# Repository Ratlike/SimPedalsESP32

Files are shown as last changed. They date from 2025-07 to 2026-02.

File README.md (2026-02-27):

# SimPedalsESP32

DIY sim racing pedals using an ESP32-S3. Supports brake, accelerator, clutch, and handbrake — shows up as a USB gamepad on your PC.

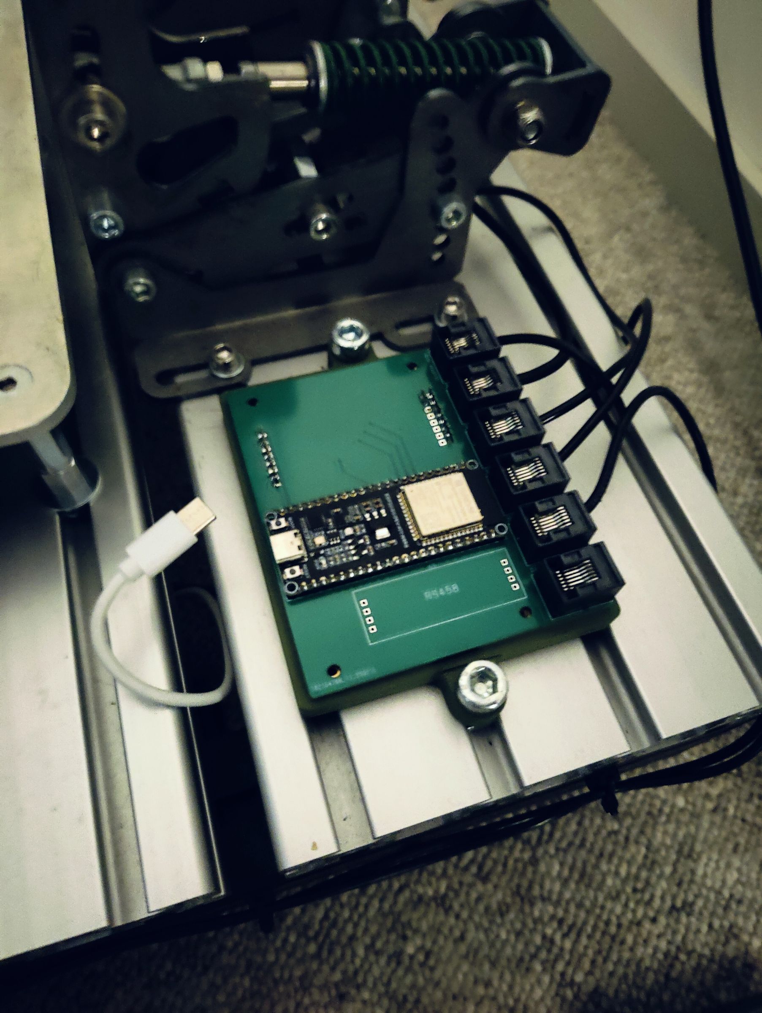
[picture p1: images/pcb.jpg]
PCB


## Hardware

- **ESP32-S3** microcontroller
- **Brake** — load cell + ADS1256 ADC
- **Accelerator & Clutch** — Hall-effect sensors
- **Handbrake** — load cell + HX711 ADC
- **2 buttons** for shifter / calibration

The `hardware/` folder has the KiCad PCB project and STEP files for a 3D-printed case.

## Building

Arduino IDE project targeting the ESP32-S3. Install the ESP32 board package, then add these libraries:

- [ADS1256](https://github.com/adienakhmad/ADS1256)
- [Joystick_ESP32S2](https://github.com/schnoog/Joystick_ESP32S2)
- [HX711](https://github.com/bogde/HX711)
- [Bounce2](https://github.com/thomasfredericks/Bounce2)

Open `SimPedalsESP32.ino` and upload.

## Calibration

1. Open a serial monitor at 115200 baud.
2. Hold **Button 1** for 3 seconds to enter calibration mode.
3. Press **Button 2** to cycle through pedals.
4. Leave each pedal at rest for 2 seconds, then press it to its max. The serial monitor shows the current raw value, min, and max in real time.
5. Hold **Button 1** for 3 seconds to save and exit.

Calibration is saved to flash and persists across power cycles.

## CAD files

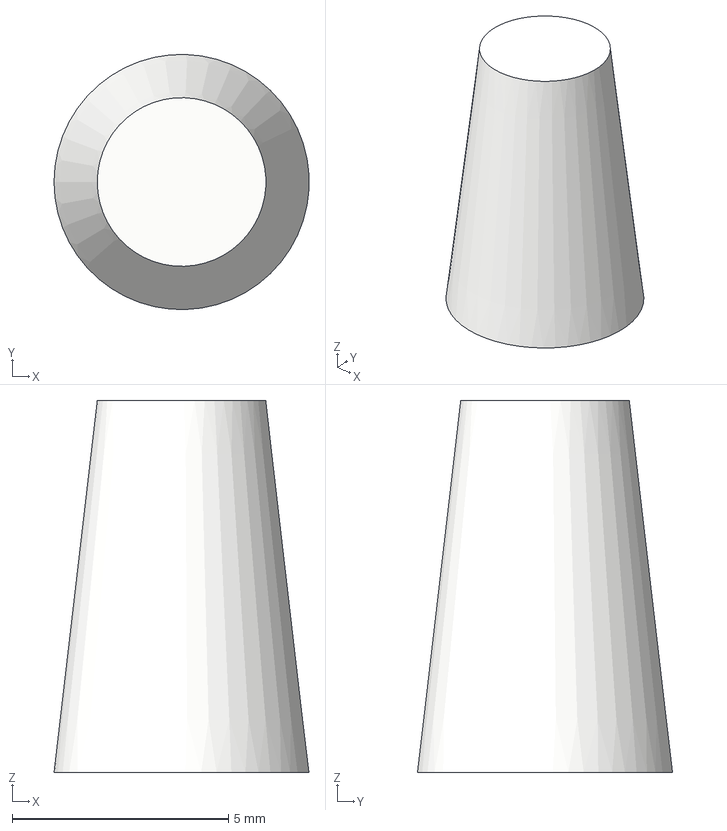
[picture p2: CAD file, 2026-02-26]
hardware/Case/LightGuide.step
5.89 x 5.90 x 8.60 mm

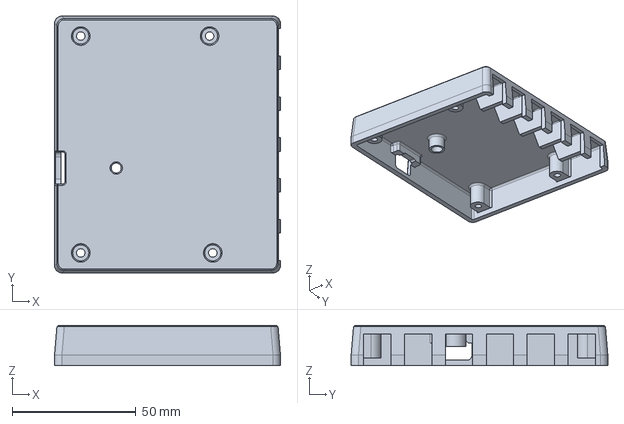
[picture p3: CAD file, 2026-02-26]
hardware/Case/Lid.step
91.3 x 103.8 x 16.2 mm

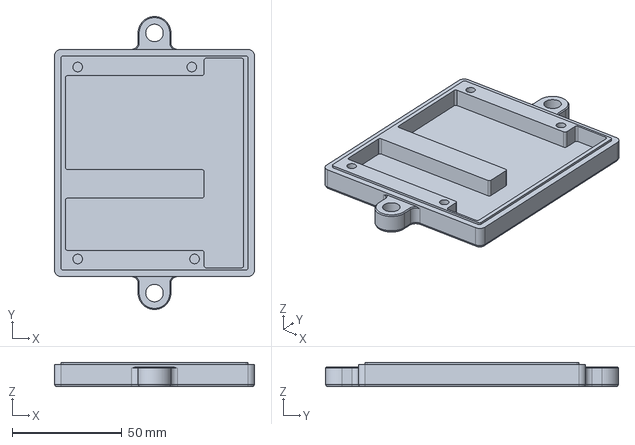
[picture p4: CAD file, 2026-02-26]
hardware/Case/Bottom.step
91.3 x 133.8 x 11.0 mm

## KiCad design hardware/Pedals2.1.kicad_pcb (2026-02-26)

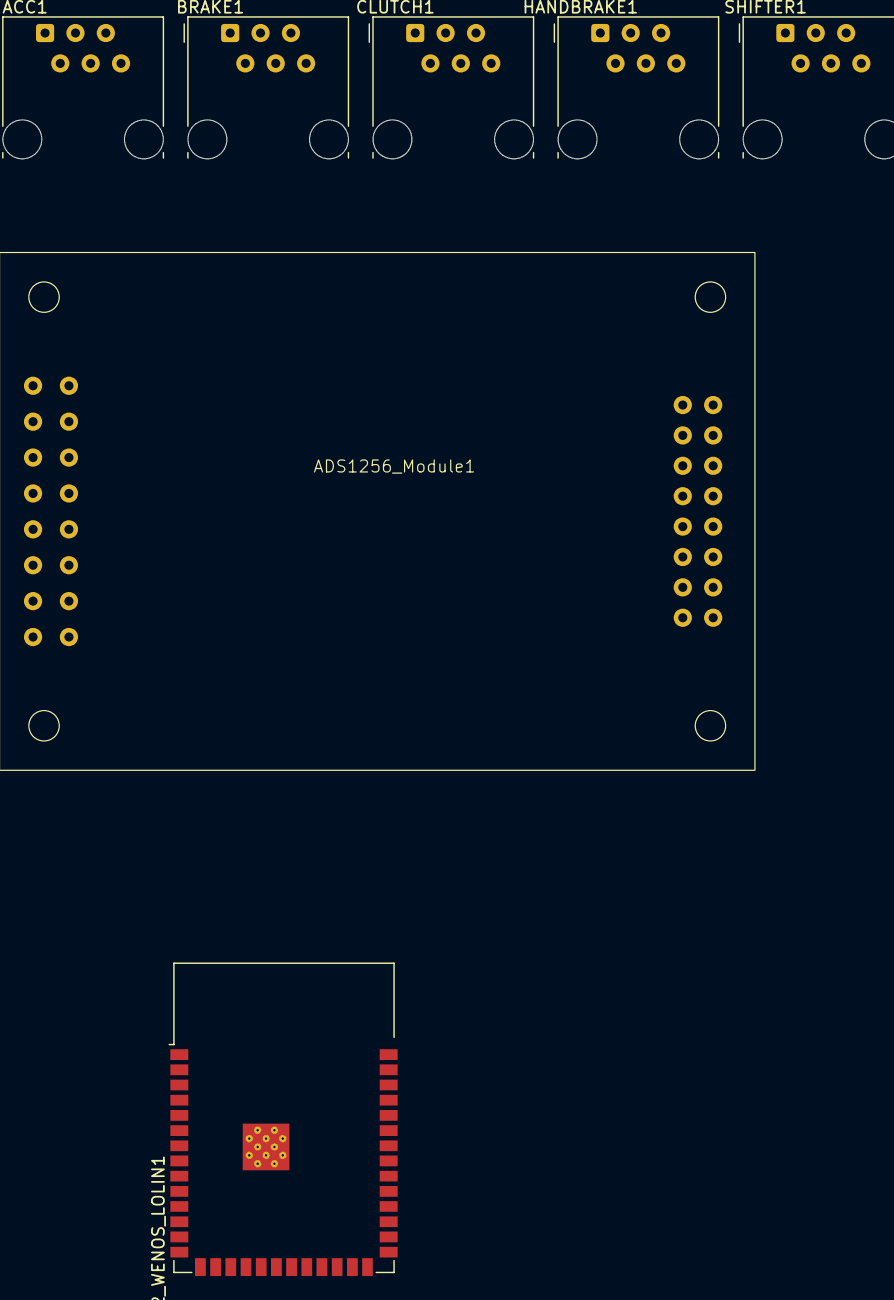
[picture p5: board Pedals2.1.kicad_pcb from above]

Board: 2 copper layers, 7 parts (0 on the bottom side), 2 nets, no tracks yet.

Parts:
ACC1: RJ12; RJ12_Amphenol_54601-x06_Horizontal
ADS1256_Module1: ADS1256 board
BRAKE1: RJ12; RJ12_Amphenol_54601-x06_Horizontal
CLUTCH1: RJ12; RJ12_Amphenol_54601-x06_Horizontal
ESP32_WENOS_LOLIN1: ESP32-S3-WROOM-1
HANDBRAKE1: RJ12; RJ12_Amphenol_54601-x06_Horizontal
SHIFTER1: RJ12; RJ12_Amphenol_54601-x06_Horizontal

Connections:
+3V3: ACC1.1, ACC1.2, BRAKE1.1, BRAKE1.2, CLUTCH1.1, CLUTCH1.2, HANDBRAKE1.1, HANDBRAKE1.2, SHIFTER1.1, SHIFTER1.2
GND: ACC1.5, ACC1.6, BRAKE1.5, BRAKE1.6, CLUTCH1.5, CLUTCH1.6, HANDBRAKE1.5, HANDBRAKE1.6, SHIFTER1.5, SHIFTER1.6

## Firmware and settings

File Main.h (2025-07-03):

// Main.h
#pragma once
//#include <ADS1256.h>

//#define PRINT_TASK_FREE_STACKSIZE_IN_WORDS

/********************************************************************/
/*                      Other defines       */
/********************************************************************/

// 2.0kHz
#define ADC_SAMPLE_RATE ADS1256_DRATE_2000SPS

/********************************************************************/
/*                      Loadcell defines                            */
/********************************************************************/
#define LOADCELL_WEIGHT_RATING_KG 200.0f
#define LOADCELL_EXCITATION_V 5.0f
#define LOADCELL_SENSITIVITY_MV_V 2.0f

// ADC defines
#define PIN_SCK 6    // 16 -->SCLK
#define PIN_MOSI 7   // 17 --> DIN
#define PIN_MISO 15  // 18 --> DOUT
#define PIN_DRDY 16  // 19 --> DRDY
#define PIN_CS 17    // 21 --> CS
#define PIN_RST 18   // 18 --> PDOWN

/********************************************************************/
/*                       Other input pins                           */
/********************************************************************/

#define CONTROLLER_BUTTON_COUNT 2
#define SHIFTER1_PIN 4
#define SHIFTER2_PIN 5
#define ACCEL_PIN_1 9
#define ACCEL_PIN_2 10
#define CLUTCH_PIN_1 11
#define CLUTCH_PIN_2 12

// HX711 pins (for handbrake)
#define HANDBRAKE_DOUT 1
#define HANDBRAKE_SCK 2

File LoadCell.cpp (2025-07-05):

// LoadCell.cpp
#include "LoadCell.h"

#include <SPI.h>
#include <ADS1256.h>
#include "Main.h"

static const float ADC_CLOCK_MHZ = 7.68f; // crystal frequency used on ADS1256
static const float ADC_VREF = 2.5f;       // voltage reference

static const int NUMBER_OF_SAMPLES_FOR_LOADCELL_OFFFSET_ESTIMATION = 1000;
static const float DEFAULT_VARIANCE_ESTIMATE = 0.2f * 0.2f;
static const float LOADCELL_VARIANCE_MIN = 0.001f;
// static const float CONVERSION_FACTOR = LOADCELL_WEIGHT_RATING_KG / (LOADCELL_EXCITATION_V * (LOADCELL_SENSITIVITY_MV_V/1000));

float updatedConversionFactor_f64 = 1.0f;
#define CONVERSION_FACTOR LOADCELL_WEIGHT_RATING_KG / (LOADCELL_EXCITATION_V * (LOADCELL_SENSITIVITY_MV_V / 1000.0f))

uint8_t global_channel0_u8, global_channel1_u8, global_channel2_u8;

ADS1256 &ADC()
{
  static ADS1256 adc(
      ADC_CLOCK_MHZ,
      ADC_VREF,
      /*useresetpin=*/false,
      PIN_DRDY, PIN_SCK, PIN_MISO, PIN_MOSI, PIN_CS); // RESETPIN is permanently tied to 3.3v

  static bool firstTime = true;
  if (firstTime)
  {
    // ensure the ADS1256 RST pin is held high via internal pull-up
    pinMode(PIN_RST, INPUT_PULLUP);
    digitalWrite(PIN_RST, HIGH);

    Serial.println("Starting ADC");
    adc.initSpi(ADC_CLOCK_MHZ);
    delay(1000);

    Serial.println("ADS: send SDATAC command");
    // adc.sendCommand(ADS1256_CMD_SDATAC);

    // start the ADS1256 with a certain data rate and gain
    adc.begin(ADC_SAMPLE_RATE, ADS1256_GAIN_64, false);

    Serial.println("ADC Started");

    adc.waitDRDY(); // wait for DRDY to go low before changing multiplexer register
    if (fabs(CONVERSION_FACTOR) > 0.01f)
    {
      adc.setConversionFactor(CONVERSION_FACTOR);
    }
    else
    {
      adc.setConversionFactor(1);
    }
    firstTime = false;
  }

  return adc;
}

void LoadCell_ADS1256::setLoadcellRating(uint8_t loadcellRating_u8) const
{
  ADS1256 &adc = ADC();
  float originalConversionFactor_f64 = CONVERSION_FACTOR;

  updatedConversionFactor_f64 = 1.0f;
  if (LOADCELL_WEIGHT_RATING_KG > 0)
  {
    updatedConversionFactor_f64 = 2.0f * ((float)loadcellRating_u8) * (CONVERSION_FACTOR / LOADCELL_WEIGHT_RATING_KG);
  }
  Serial.print("OrigConversionFactor: ");
  Serial.print(originalConversionFactor_f64);
  Serial.print(",     NewConversionFactor:");
  Serial.println(updatedConversionFactor_f64);

  // adc.setConversionFactor( updatedConversionFactor_f64 );
  adc.setConversionFactor(1);
}

LoadCell_ADS1256::LoadCell_ADS1256(uint8_t channel0, uint8_t channel1)
    : _zeroPoint(0.0f), _varianceEstimate(DEFAULT_VARIANCE_ESTIMATE)
{

  global_channel0_u8 = channel0;
  global_channel1_u8 = channel1;
  ADC().setChannel(channel0, channel1); // Set the MUX for differential between ch0 and ch1
  // ADC().setChannel(channel1, channel0);   // Set the MUX for differential between ch1 and ch0
}

float LoadCell_ADS1256::getReadingKg() const
{
  extern volatile float g_lastBrakeKg;
  return g_lastBrakeKg * updatedConversionFactor_f64 - (_zeroPoint + 3.0f * _standardDeviationEstimate);
}

void LoadCell_ADS1256::setZeroPoint()
{
  ADS1256 &adc = ADC();

  Serial.println("ADC: Identify loadcell offset");

  float loadcellOffset = 0.0f; // same name as before
  for (long i = 0; i < NUMBER_OF_SAMPLES_FOR_LOADCELL_OFFFSET_ESTIMATION; ++i)
  {
    adc.waitDRDY();                                                           // block until fresh conversion
    float readingKg = adc.readCurrentChannel() * updatedConversionFactor_f64; // keep existing scale
    loadcellOffset += readingKg;
  }
  loadcellOffset /= NUMBER_OF_SAMPLES_FOR_LOADCELL_OFFFSET_ESTIMATION;

  Serial.print("Offset ");
  Serial.println(loadcellOffset, 10);

  _zeroPoint = loadcellOffset;
}

void LoadCell_ADS1256::estimateVariance()
{
  ADS1256 &adc = ADC();

  Serial.println("ADC: Identify loadcell variance");

  float varNormalizer = 1.0f /
                        (float)(NUMBER_OF_SAMPLES_FOR_LOADCELL_OFFFSET_ESTIMATION - 1); // unchanged name
  float varEstimate = 0.0f;
  for (long i = 0; i < NUMBER_OF_SAMPLES_FOR_LOADCELL_OFFFSET_ESTIMATION; ++i)
  {
    adc.waitDRDY();
    float loadcellReading =
        adc.readCurrentChannel() * updatedConversionFactor_f64 - _zeroPoint; // identical bias removal
    varEstimate += sq(loadcellReading) * varNormalizer;
  }

  _standardDeviationEstimate = sqrtf(varEstimate);

  Serial.println("Variance est.:");
  Serial.println(varEstimate);
  Serial.println("Stddev est.:");
  Serial.println(_standardDeviationEstimate);

  if (varEstimate < LOADCELL_VARIANCE_MIN)
  {
    varEstimate = LOADCELL_VARIANCE_MIN;
  }
  varEstimate *= 9.0f; // keep 3 σ envelope logic
  _varianceEstimate = varEstimate;
}

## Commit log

2025-07-05 Fixed broken setZeroPoint and estimateVariance.
    [LoadCell.cpp, SimPedalsESP32.ino]
2025-07-06 Offload Hall sensor sampling to core 1, flush S/H cap, and add EMA filtering
    - Move ACCEL_PIN_2/CLUTCH_PIN_2 reads from loop()’s analogRead() into a FreeRTOS task pinned to core 1 at 1 kHz
    - Perform a dummy ADC read before each real sample to flush the sample-and-hold capacitor and prevent crosstalk
    - Apply exponential moving average (α = 0.30) to accelerator and clutch readings for jitter reduction
    [HallSampler.cpp, SimPedalsESP32.ino]
2025-07-10 Improved brake pedal responsiveness. Fixed brake zero point calculation not executing.
    [SimPedalsESP32.ino]
2026-02-26 Hardware project files added
    [Pedals2.1.kicad_pcb, Pedals2.1.kicad_sch]
2026-02-26 STEP files for case
    [Bottom.step, Lid.step, LightGuide.step]
2026-02-26 Image of finished device
2026-03-09 Replace USB CDC serial with HID feature reports for calibration
    Eliminates the CDC COM port to make the device a pure HID gamepad,
    preventing Windows re-enumeration when SimHub opens/closes the port.
    Calibration is now controlled via WebHID feature reports (GET 0x04,
    SET 0x05) from a browser-based tool instead of physical buttons.
